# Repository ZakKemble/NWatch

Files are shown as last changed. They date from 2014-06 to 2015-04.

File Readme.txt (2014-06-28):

N|Watch - DIY Digital Wristwatch
http://blog.zakkemble.co.uk/diy-digital-wristwatch/

The firmware .hex and .eep files are compiled for ATmega328P

Fuses for ATmega328/328P
Internal RC 8MHz 6 CK/14CK + 65ms startup
Bootloader enabled, 256 words (512 bytes)
Serial program (SPI) enabled
Brown-out at 1.8V
High:		0xDE
Low:		0xE2
Extended:	0x06

./utils/bitmapConverter.exe
Utility to convert images (in ./imgs/) to pixel byte array

Font used for the large numbers on the main time display is AgencyFB Bold Wide available at http://www.fontsner.com/font/AgencyFBBoldWide-37966.html
My productions are published under GNU GPL v3 (see License.txt).

--------

Zak Kemble
contact@zakkemble.co.uk

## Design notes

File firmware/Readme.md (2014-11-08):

About these hex and eep files
=============================

### optiboot.hex
Optiboot UART bootloader. Baud set to 57600 for maximum compatibility.

### optiboot_superspeed.hex
Optiboot UART bootloader. Baud set to 1000000 which is the fastest an 8MHz AVR can run its UART at. Reduces upload time from ~14 seconds to ~5 seconds (27174 bytes).  
Tested on Windows and Linux with CH340G USB-serial converter. Should work with most other converters. However AVRDUDE on Linux needs a minor modification to support 1Mb, see this - https://github.com/zkemble/avrdude/tree/custombaud

### watch_eng.hex
The main program in English.

### watch_rus.hex
The main program in Russian.

### watch.eep
EEPROM data. This must be uploaded along with `watch_(lang).hex`, it contains the beep tunes and other bits of data.

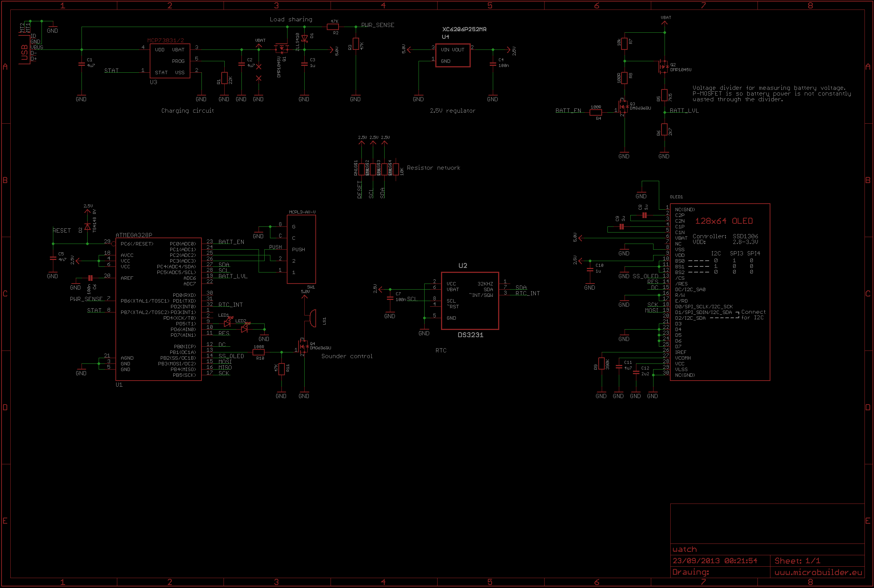
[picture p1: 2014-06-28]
hardware/watch/1.1/schematic.png

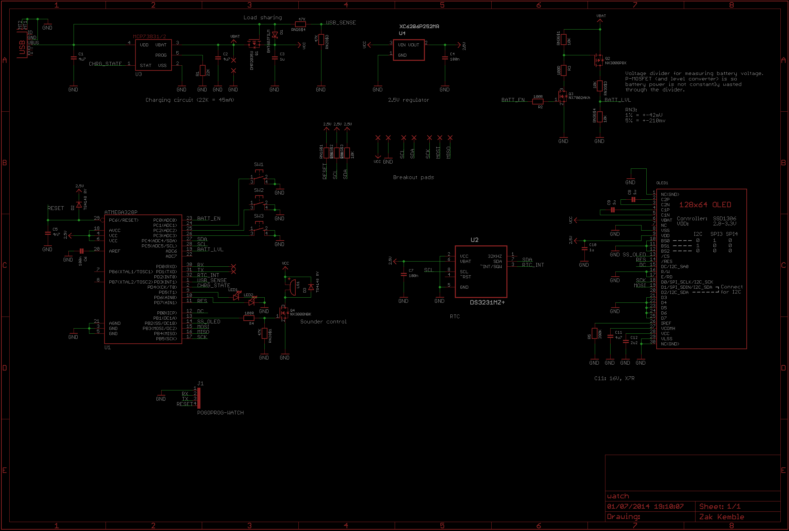
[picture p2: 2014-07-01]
hardware/watch/1.3/schematic.png

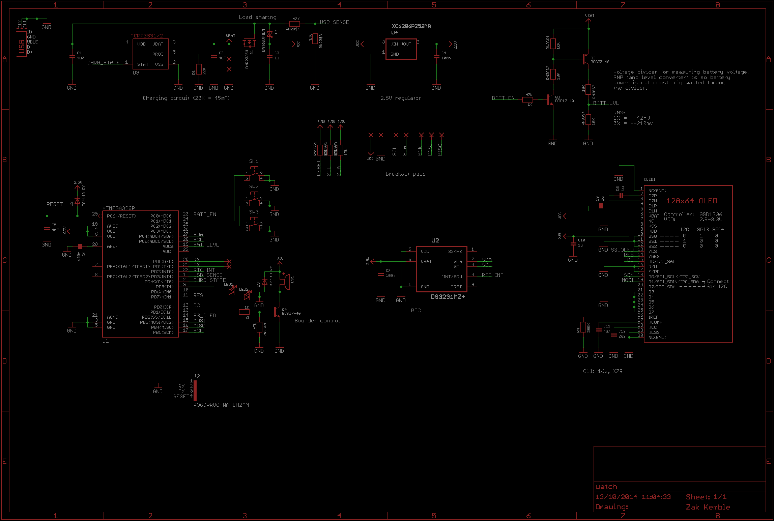
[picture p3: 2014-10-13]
hardware/watch/1.4/schematic.png

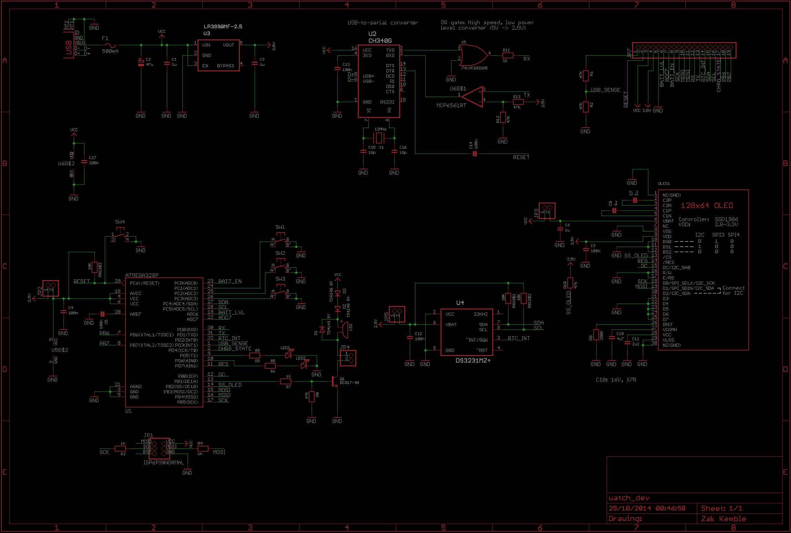
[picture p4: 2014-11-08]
hardware/dev/1.1/schematic.png

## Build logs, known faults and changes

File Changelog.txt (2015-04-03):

2015-04-03:
	Software:
	- Added support for SH1106 OLEDs, see OLED_CONTROLLER in config.h

2014-11-15:
	Software:
	- Fixed issue for when RTC isn't connected

2014-11-08:
	Software:
	- Updated Russian translation (day of week images)

	Hardware:
	- Released N|WatchDev designs (dev board version of the watch)

2014-10-29:
	Software:
	- Added 12 hour time option
	- Russian translation, thanks to Onatsky Sergei (Le_Fleurs (-at-) mail (-dot-) ru)
	- Bootloader baud changed from 76800 to 57600 (Linux doesn't like 76800)

2014-10-20:
	Software:
	- Fixed alarm bug

2014-10-13:
	Software:
	- Added early battery undervoltage cutoff. Improves battery lifespan by not letting the voltage go so low and the RTC will continue working since the battery's own PCM hasn't kicked in yet
	- Slightly reduced power consumption by going into power save sleep instead of idle sleep if no other peripherals are in use
	- Various code optimisations

	Hardware:
	N|Watch (v1.4):
	- Q2, Q3, Q4 MOSFETs changed to BJTs (BC817-40 & BC807-40)
	- R2, R3 100R gate resistors changed to 47K and 1K
	- R4 has been removed (now all resistors in RN3 are being used)
	- Pogo pads are now 2mm apart instead of 1.27mm (was hard to solder the pogo adapter)

2014-06-30:
	Software:
	- Fixed tune priority not resetting

2014-06-28:
	Software:
	- Added a bootloader (slightly modified Optiboot, added support for ATmega328 non-P and reading/writing EEPROM)
	- Reduced flash and RAM usage (Flash: 29156 -> 26702 (2454), RAM: 1407 -> 1300 (107))
	- Added support for playing tunes
	- Alarms are loaded from EEPROM as needed instead of having them hanging around in RAM all the time
	- Lots of bug fixes, heres some:
		Wonkiness if EEPROM wasn't programmed
		Alarms not going off on the correct day
		If an alarm goes off but is not cancelled by the user the watch would stay on
		Watch waking up when it's not supposed to
	- Bunch more stuff...

	Hardware:
	N|Watch (v1.3):
	- 3 Separate buttons instead of a 3 way nav button
	- MOSFETs have been changed to more suitable types (DMG6968s were total overkill)
	- Thinner PCB traces allowing components to be packed closer together
	- Breakout pads for power, I2C, UART and SPI

2013-09-25:
	- Initial release

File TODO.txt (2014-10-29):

global.c system.c pwrmgr.c - fix up this code! lots of little (but rare) issues with interrupts happening just before going to power down sleep
draw.c - also fix up this, cleanup that struct image_s stuff and maybe convert draw_bitmap_do() to ASM to see if its any faster?
millis.c/millis_isr.s - use flags that are processed in the ISR instead? also reduce millis resolution to 4ms? nothing in the code really needs 1ms res
bool/BOOL

Make a better readme
Arduino stuff

Alarm snooze
Options for alarm snooze
Improve alarms menu
	- Use new WE/TU icon things
Improve games menu
Options for setting what up and down buttons do when on the main watch display (open stopwatch/alarms/games etc)
Make menu option name animated, move off then back on or something
sleep mode options
	- Off
	- Low power (dim screen)
Reduce CPU clock if animations are disabled (and at other times too?)
Update the display less often (saves power)
	- Only draw when needed
	- Seperate logic and drawing
Sometimes the sounder 'pops' due to bad waveform output
Options for LEDs (brightness etc)
Fancy USB plugged in screen anim?
Countdown timer
More games?
Option to return to main diplay after going into standby

Finish support for DS1307, MCP7940x and internal RTC sources
Finish support for LED flash patterns
Something to show sunrise and sunset times? User will need to enter their latitude.
Record time of USB unplug

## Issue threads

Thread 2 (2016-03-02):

cant wake from sleep,uses lots of battery too

dunk8888, 2016-03-02:
how do i wake watch from screen off sleep mode,no buttons seem to wake it up.

zkemble, 2016-03-05:
Any button press should wake the watch. Do all of the buttons work when the watch is on?

dunk8888, 2016-03-05:
yes all buttons work,this is only pcb desighn,i use it as a little allarm
clock and it seems to use a 300mah battery overnight even when screen is
off,if i leave for more than a few minutes it doesnt like to wake up,i have
to pull battery then plug back in,i love the car game by the way,i love the
hole thing,verry smart indeed.

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

zkemble, 2016-03-05:
Thanks :D Hmm, did you load the .eep file? Maybe double check for any short circuits too. What's the current draw from the battery like?

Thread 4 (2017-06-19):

Code...

lechatvert, 2017-06-19:
I can't seem to find the exact code for this watch. I really like the interface but I'm just a beginner so I can't really do it. If you can, I would highly appreciate having the code so I can make this watch. Also, if you can, I would like having instructions on how to make it with an Arduino, since it's a lot easier to use. I'm planning to use the Pro Mini or the Pro Micro. Thanks in advance.

lechatvert, 2017-06-20:
Oh, by the way, I just saw the closed issue about arduinos. But, if possible, can you explain to me how to flash the code on the chip and what I will need to flash it.

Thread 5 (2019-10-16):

im noob ..error

cheese0307, 2019-10-16:
C:\Users\ADMINI~1\AppData\Local\Temp\cc9zl9qr.ltrans0.ltrans.o: In function `oled_flush':

C:\Users\ADMINI~1\AppData\Local\Temp\arduino_build_31448\sketch/oled.c:108: undefined reference to `spi_transfer_nr'

C:\Users\ADMINI~1\AppData\Local\Temp\arduino_build_31448\sketch/oled.c:109: undefined reference to `spi_transfer_nr'

C:\Users\ADMINI~1\AppData\Local\Temp\arduino_build_31448\sketch/oled.c:110: undefined reference to `spi_transfer_nr'

C:\Users\ADMINI~1\AppData\Local\Temp\arduino_build_31448\sketch/oled.c:112: undefined reference to `spi_transfer_nr'

C:\Users\ADMINI~1\AppData\Local\Temp\arduino_build_31448\sketch/oled.c:113: undefined reference to `spi_transfer_nr'

C:\Users\ADMINI~1\AppData\Local\Temp\cc9zl9qr.ltrans0.ltrans.o:C:\Users\ADMINI~1\AppData\Local\Temp\arduino_build_31448\sketch/oled.c:114: more undefined references to `spi_transfer_nr' follow

collect2.exe: error: ld returned 1 exit status

exit status 1
为开发板 Arduino Leonardo 编译时出错。

zkemble, 2019-10-16:
N|Watch is not an Arduino compatible project. You need to use [Atmel Studio](https://www.microchip.com/mplab/avr-support/atmel-studio-7).

Closed 2019-10-17.

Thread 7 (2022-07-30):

Fuses for ATmega328/328P

7918514, 2022-07-30:
You have fuses:
High: 0xDE
Low: 0xE2
Extended: 0x06
This is right? These fuses are for external quartz.

ZakKemble, 2022-07-30:
No, they're correct. I think you have got the high and low fuses mixed up.

7918514, 2022-07-30:
I beg your pardon. You're right. I looked carelessly. I'm used to Low, High, Extended.
Thanks!

Closed 2022-07-30.

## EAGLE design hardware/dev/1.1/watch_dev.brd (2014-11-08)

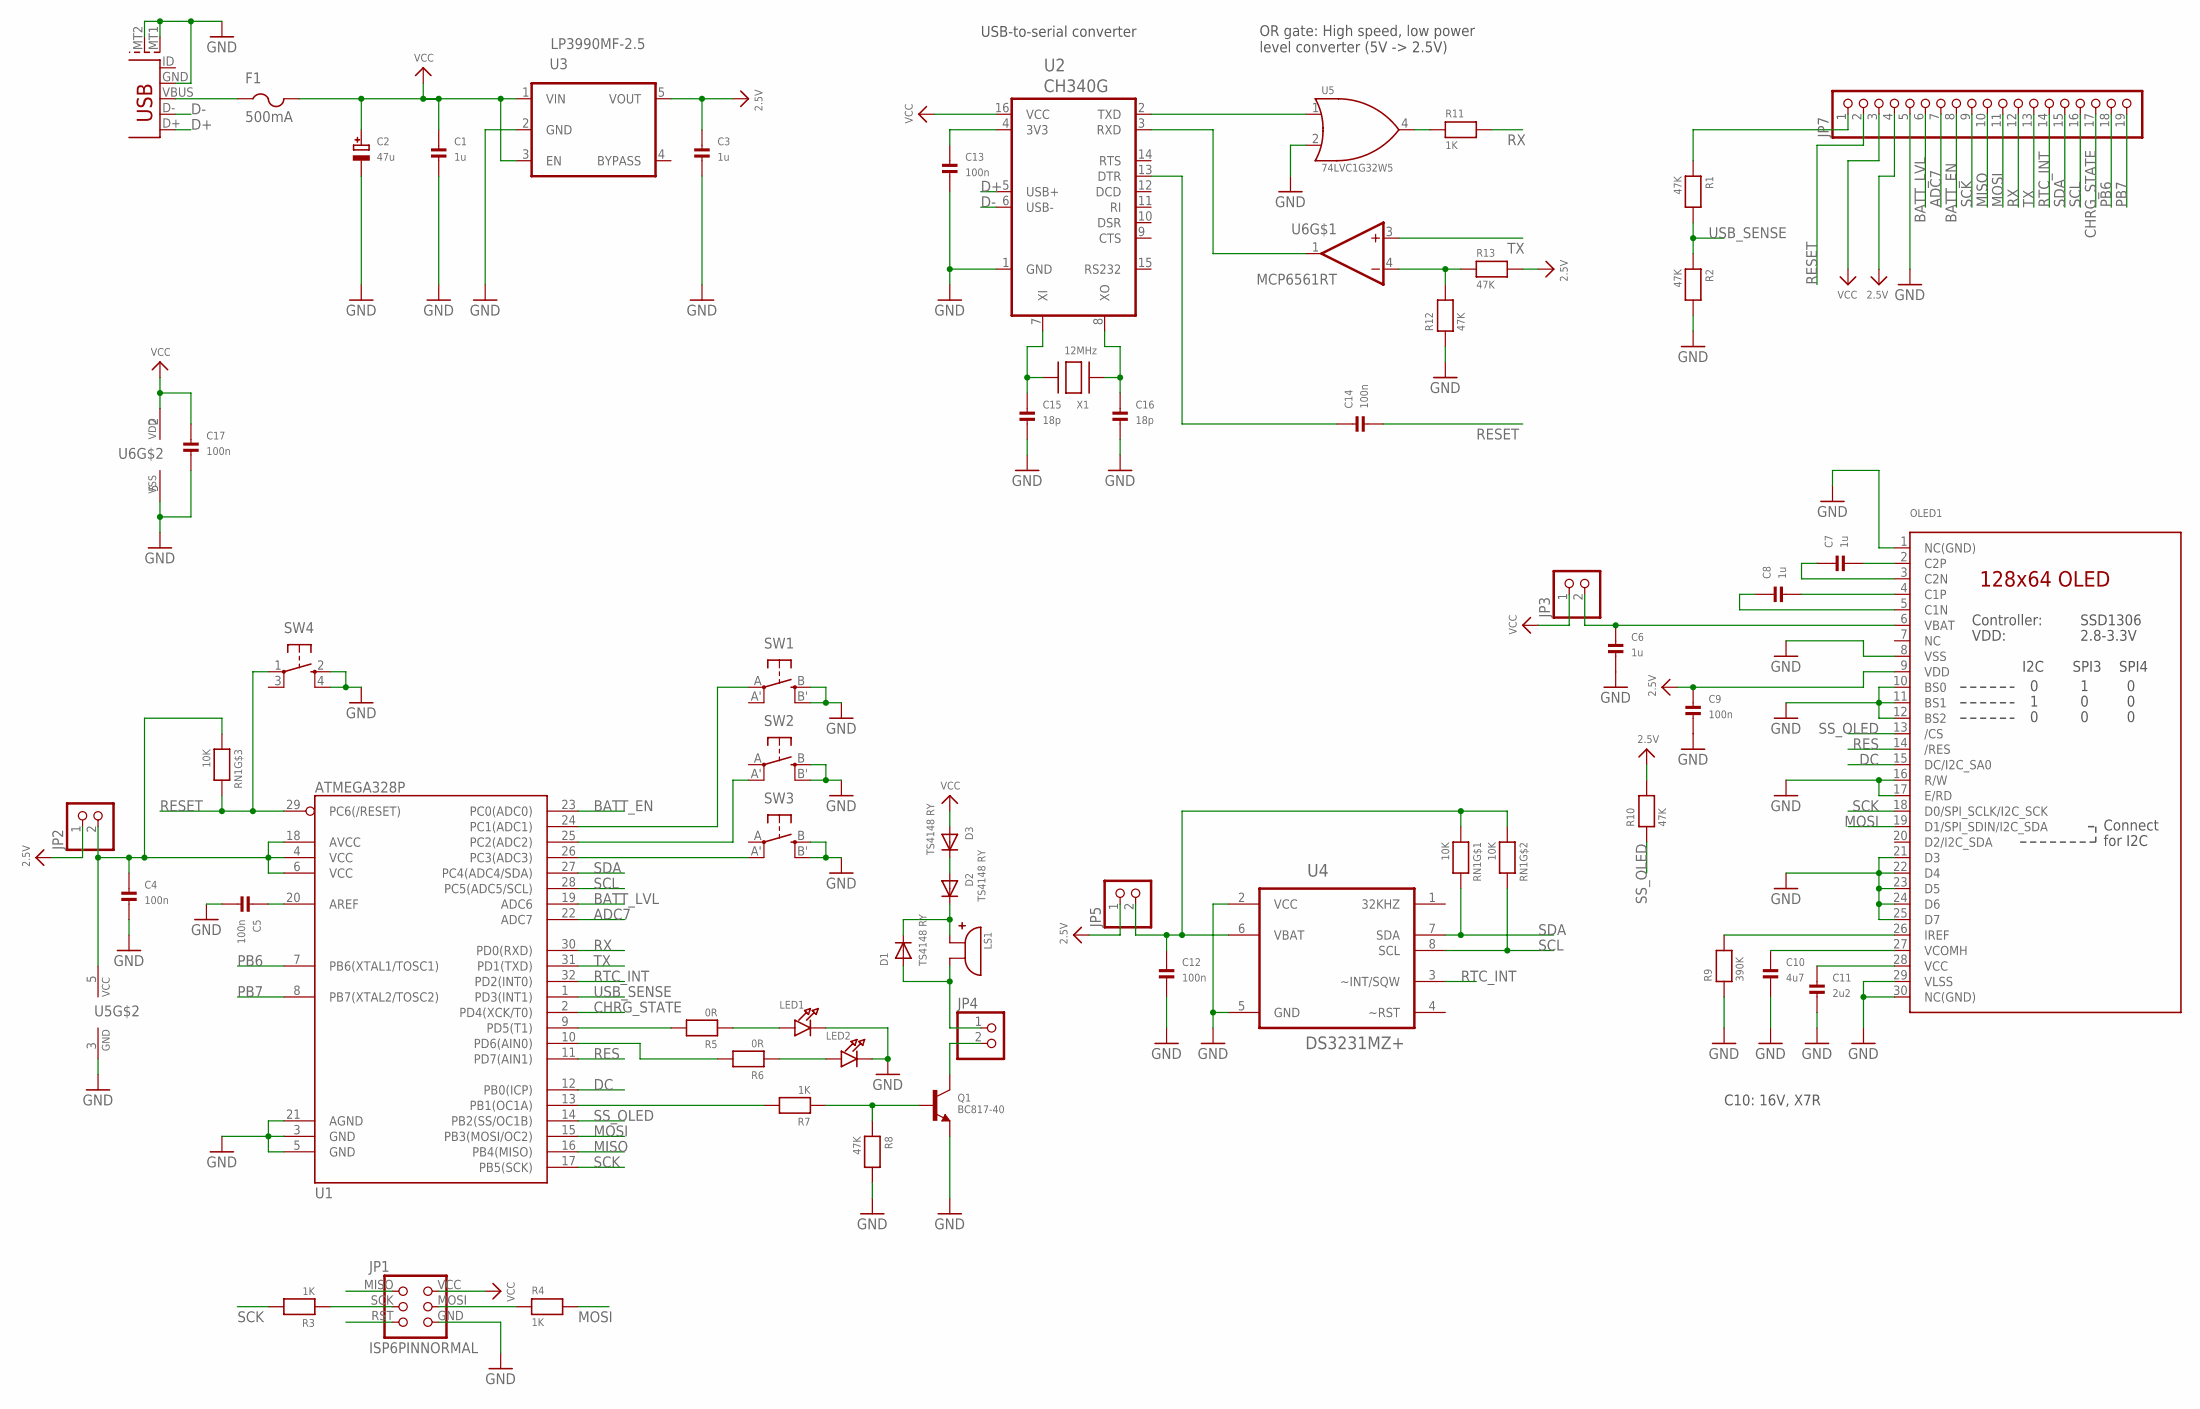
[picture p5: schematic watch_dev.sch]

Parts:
C1, C3, C6, C7, C8: 1u; 0805
C2: 47u; PANASONIC_C
C4, C5, C9, C12, C13, C14, C17: 100n; 0805
C10: 4u7; 0805
C11: 2u2; 0805
C15, C16: 18p; 0805
D1, D2, D3: TS4148 RY; 0805_DIODE
F1: 500mA; 1206
JP1: ISP6PINNORMAL; ISP6PIN
JP2, JP3, JP4, JP5: PINHD-1X2; 1X02
JP7: PINHD-1X19; 1X19
LED1, LED2: LED0805; CHIPLED_0805
LS1: ABMT-801-RC; PIEZO
OLED1: DISP_OLED_UG-2864HSWEG01_NOOUTLINE; UG-2864HSWEG01_1.3_WRAPAROUND
Q1: BC817-40; SOT23-WIDE
R1, R2, R8, R10, R12, R13: 47K; 0805
R3, R4, R7, R11: 1K; 0805
R5, R6: 0R; 0805
R9: 390K; 0805
RN1: 10K; RESPACK_4X0603
SW1, SW2, SW3: SPST_TACTMC32882; TACT_SMD4
SW4: SPST_TACTKMR2; KMR2
U1: ATMEGA328P; TQFP32-08
U2: CH340G; SOIC16_SMPAD
U3: LP3990MF-2.5; SOT95P275X110-5N
U4: DS3231MZ+; SOIC8_150MIL_SMPAD
U5: 74LVC1G32W5; SOT95P275X110-5N
U6: MCP6561RT; SOT95P275X110-5N
USB1: USB-MICROBLARGEPAD; USB-MICROB_LARGEPAD
X1: 12MHz; NX5032

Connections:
2.5V: C3.1, C9.1, JP2.1, JP5.1, JP7.4, OLED1.9 (VDD), R10.2, R13.2, U3.5 (VOUT)
ADC7: JP7.7, U1.22 (ADC7)
BATT_EN: JP7.8, U1.23 (PC0(ADC0))
BATT_LVL: JP7.6, U1.19 (ADC6)
CHRG_STATE: JP7.17, U1.2 (PD4(XCK/T0))
D+: U2.5 (USB+), USB1.D+
D-: U2.6 (USB-), USB1.D-
DC: OLED1.15 (DC/I2C_SA0), U1.12 (PB0(ICP))
GND: C1.2, C2.-, C3.2, C4.2, C5.2, C6.2, C9.2, C10.2, C11.2, C12.2, C13.2, C15.2, C16.2, C17.2, JP1.GND (6), JP7.5, LED1.C, LED2.C, OLED1.1 (NC(GND)), OLED1.8 (VSS), OLED1.10 (BS0), OLED1.11 (BS1), OLED1.12 (BS2), OLED1.16 (R/W), OLED1.17 (E/RD), OLED1.21 (D3), OLED1.22 (D4), OLED1.23 (D5), OLED1.24 (D6), OLED1.25 (D7), OLED1.29 (VLSS), OLED1.30 (NC(GND)), Q1.2 (E), R2.2, R8.2, R9.1, R12.1, SW1.B (S), SW1.B' (S1), SW2.B (S), SW2.B' (S1), SW3.B (S), SW3.B' (S1), SW4.2 (S), SW4.4 (S1), U1.3 (GND), U1.5 (GND), U1.21 (AGND), U2.1 (GND), U3.2 (GND), U4.2 (VCC), U4.5 (GND), U5.2 (B), U5.3 (GND), U6.5 (VSS), USB1.GND, USB1.MT1 (SHEILD1), USB1.MT2 (SHEILD2)
MISO: JP1.MISO (1), JP7.10, U1.16 (PB4(MISO))
MOSI: JP7.11, OLED1.19 (D1/SPI_SDIN/I2C_SDA), R4.2, U1.15 (PB3(MOSI/OC2))
unnamed: C5.1, U1.20 (AREF)
unnamed: SW1.A, U1.24 (PC1(ADC1))
unnamed: C7.2, OLED1.2 (C2P)
unnamed: SW3.A' (P1), U1.26 (PC3(ADC3))
unnamed: OLED1.26 (IREF), R9.2
unnamed: JP7.1, R1.1
unnamed: D1.1 (A), JP4.1, LS1.2 (GND)
unnamed: Q1.1 (B), R7.1, R8.1
unnamed: SW2.A' (P1), U1.25 (PC2(ADC2))
unnamed: F1.1, USB1.VBUS
unnamed: R5.2, U1.9 (PD5(T1))
unnamed: C6.1, JP3.2, OLED1.6 (VBAT)
unnamed: C8.1, OLED1.5 (C1N)
unnamed: C8.2, OLED1.4 (C1P)
unnamed: C7.1, OLED1.3 (C2N)
unnamed: R6.2, U1.10 (PD6(AIN0))
unnamed: C4.1, JP2.2, RN1.3 (1), U1.4 (VCC), U1.6 (VCC), U1.18 (AVCC), U5.5 (VCC)
unnamed: JP4.2, Q1.3 (C)
unnamed: C10.1, OLED1.27 (VCOMH)
unnamed: C11.1, OLED1.28 (VCC)
unnamed: C15.1, U2.7 (XI), X1.P$2
unnamed: JP1.SCK (3), R3.1
unnamed: C16.1, U2.8 (XO), X1.P$1
unnamed: JP1.MOSI (4), R4.1
unnamed: C13.1, U2.4 (3V3)
unnamed: U2.2 (TXD), U5.1 (A)
unnamed: R11.1, U5.4 (Y)
unnamed: LED1.A, R5.1
unnamed: LED2.A, R6.1
unnamed: C14.1, U2.13 (DTR)
unnamed: C12.1, JP5.2, RN1.1, RN1.2 (1), U4.6 (VBAT)
unnamed: D1.2 (C), D2.2 (C), LS1.1 (VCC)
unnamed: D2.1 (A), D3.2 (C)
unnamed: U2.3 (RXD), U6.1 (OUT)
unnamed: R12.2, R13.1, U6.4 (-IN)
PB6: JP7.18, U1.7 (PB6(XTAL1/TOSC1))
PB7: JP7.19, U1.8 (PB7(XTAL2/TOSC2))
PIEZO: R7.2, U1.13 (PB1(OC1A))
RES: OLED1.14 (/RES), U1.11 (PD7(AIN1))
RESET: C14.2, JP1.RST (5), JP7.2, RN1.6 (2), SW4.1, U1.29 (PC6(/RESET))
RTC_INT: JP7.14, U1.32 (PD2(INT0)), U4.3 (~INT/SQW)
RX: JP7.12, R11.2, U1.30 (PD0(RXD))
SCK: JP7.9, OLED1.18 (D0/SPI_SCLK/I2C_SCK), R3.2, U1.17 (PB5(SCK))
SCL: JP7.16, RN1.7 (2), U1.28 (PC5(ADC5/SCL)), U4.8 (SCL)
SDA: JP7.15, RN1.8 (2), U1.27 (PC4(ADC4/SDA)), U4.7 (SDA)
SS_OLED: OLED1.13 (/CS), R10.1, U1.14 (PB2(SS/OC1B))
TX: JP7.13, U1.31 (PD1(TXD)), U6.3 (+IN)
USB_SENSE: R1.2, R2.1, U1.1 (PD3(INT1))
VCC: C1.1, C2.+, C17.1, D3.1 (A), F1.2, JP1.VCC (2), JP3.1, JP7.3, U2.16 (VCC), U3.1 (VIN), U3.3 (EN), U6.2 (VDD)

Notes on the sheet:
C10: 16V, X7R
USB-to-serial converter
OR gate: High speed, low power level converter (5V -> 2.5V)

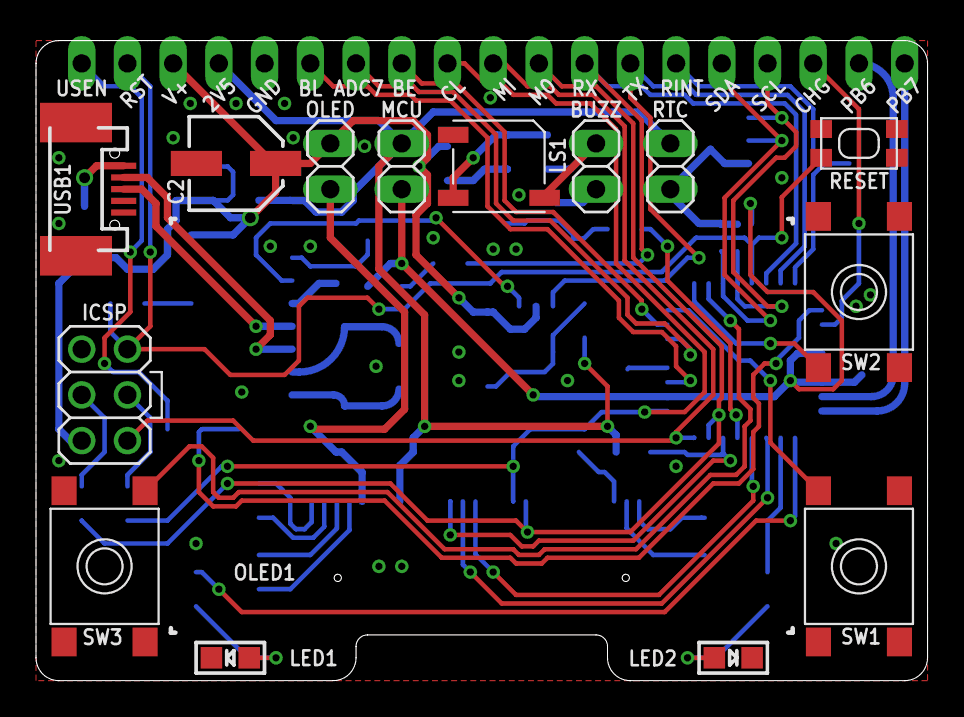
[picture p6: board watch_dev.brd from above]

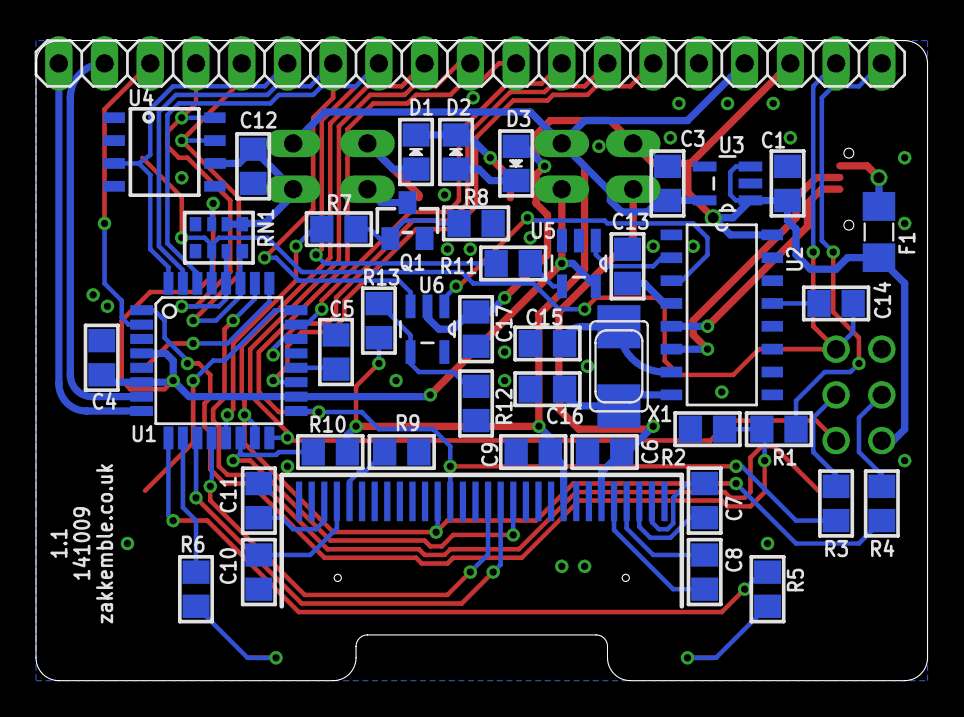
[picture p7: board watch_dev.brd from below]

Board: 2 copper layers, 49.5 x 35.6 mm, 58 parts (43 on the bottom side), 60 nets.

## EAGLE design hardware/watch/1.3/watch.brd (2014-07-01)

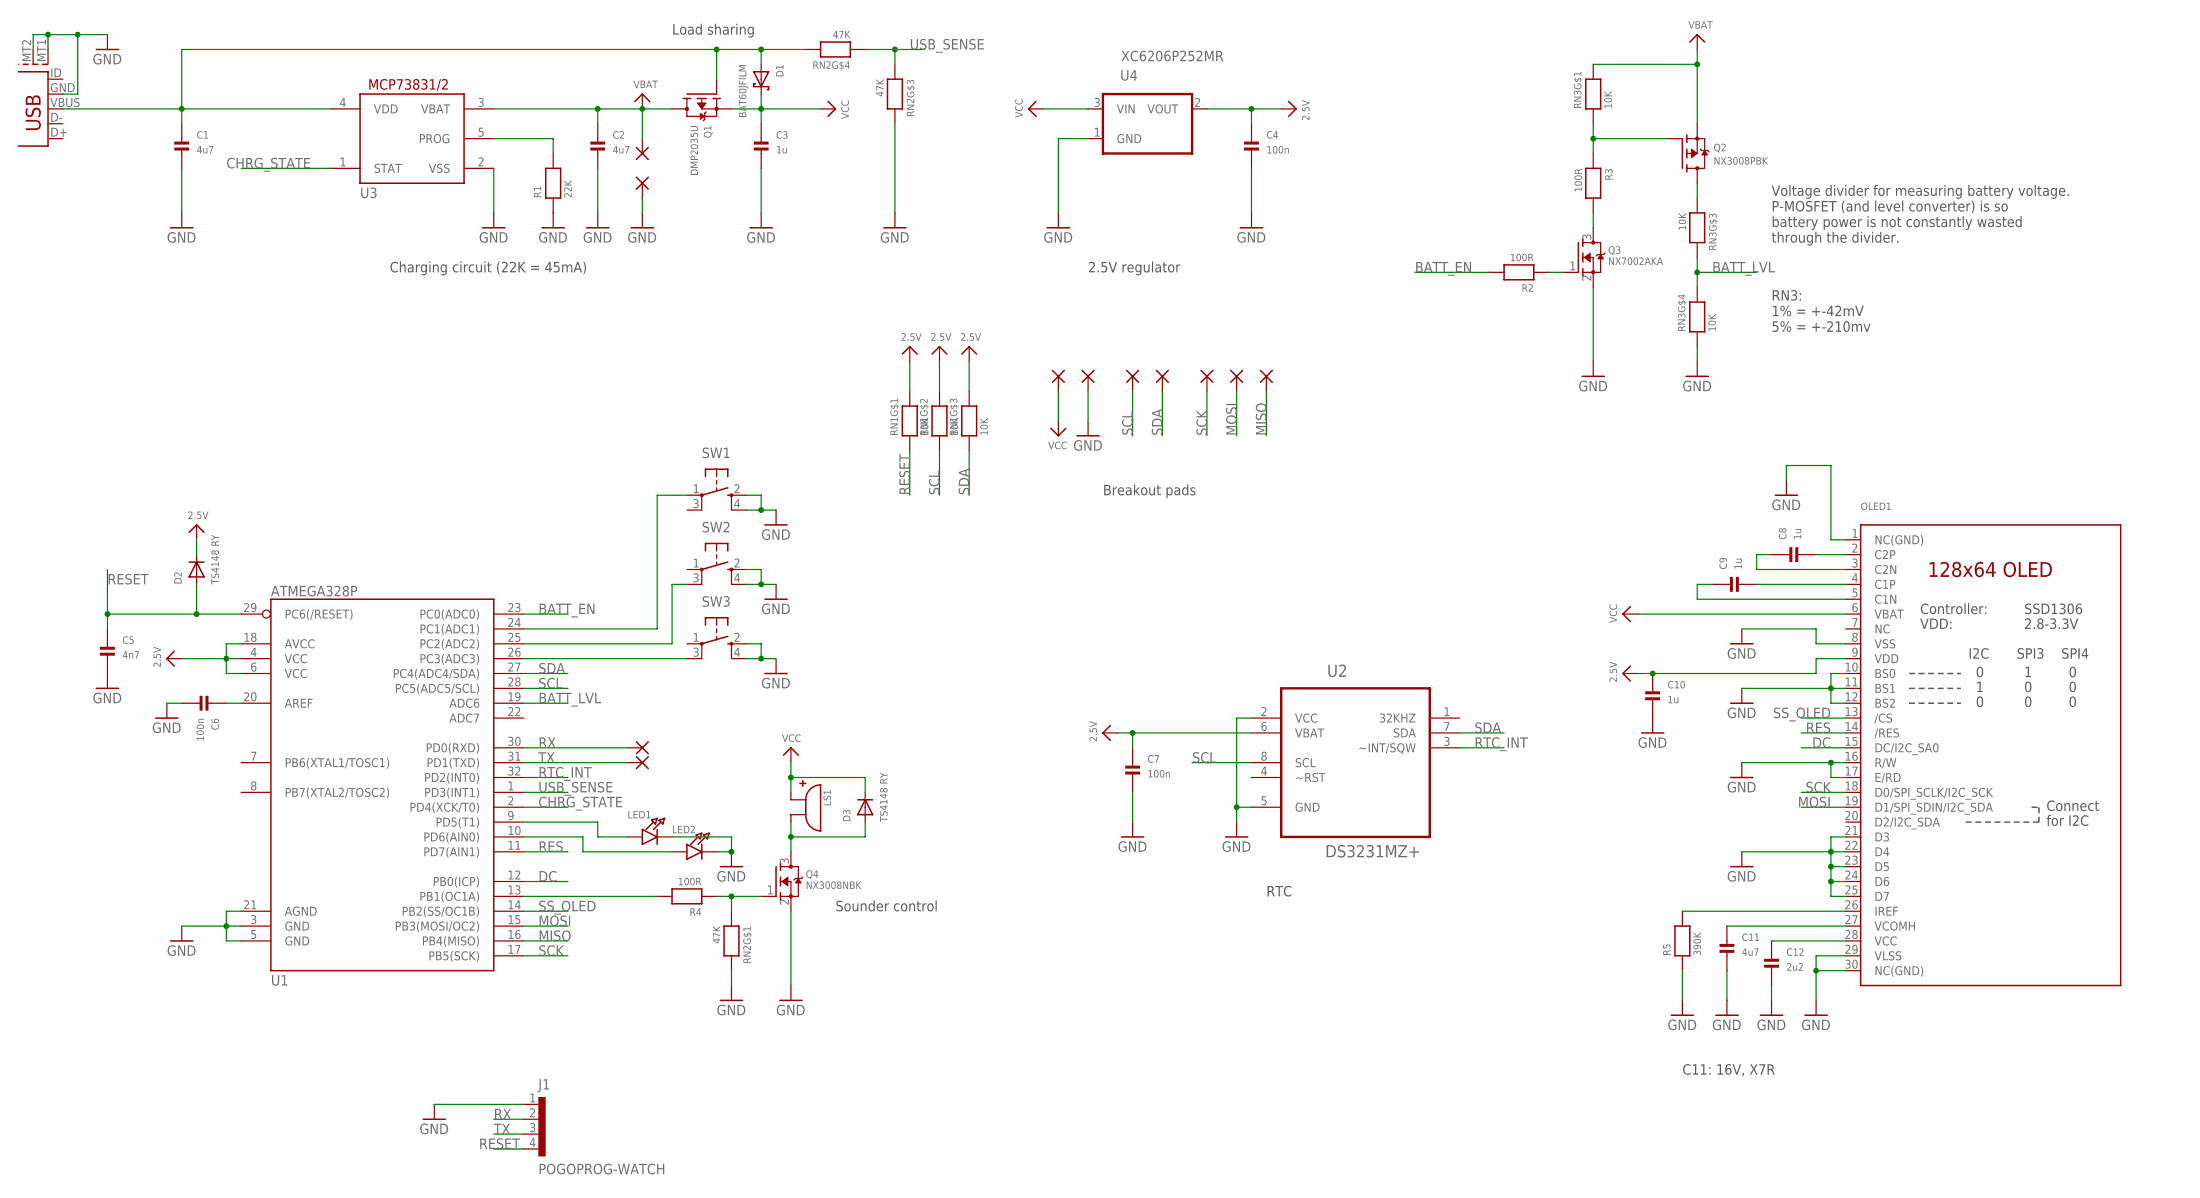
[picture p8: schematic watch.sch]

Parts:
C1, C2, C11: 4u7; 0805
C3, C8, C9, C10: 1u; 0805
C4, C6, C7: 100n; 0805
C5: 4n7; 0805
C12: 2u2; 0805
D1: BAT60JFILM; SOD-323
D2, D3: TS4148 RY; DIODE0805
J1: POGOPROG-WATCH; POGOPROG_WATCH
LED1, LED2: LED0805; CHIPLED_0805
LS1: ABMT-801-RC; PIEZO
OLED1: DISP_OLED_UG-2864HSWEG01_NOOUTLINEWATCH; UG-2864HSWEG01_1.3_WRAPAROUND_WATCH
PAD1, PAD2, PAD3, PAD4, PAD5, PAD6, PAD7, PAD8, PAD10, PAD11, PAD12: SMD2; SMD1,27-2,54
Q1: DMP2035U; SOT23-WIDE
Q2: NX3008PBK; SOT23-WIDE
Q3: NX7002AKA; SOT23-WIDE
Q4: NX3008NBK; SOT23-WIDE
R1: 22K; 0805
R2, R3, R4: 100R; 0805
R5: 390K; 0805
RN1, RN3: 10K; RESPACK_4X0603
RN2: 47K; RESPACK_4X0603
SW1, SW2, SW3: SPST_TACTRA; TACT_SMD2
U1: ATMEGA328P; TQFP32-08
U2: DS3231MZ+; SOIC8_150MIL
U3: MCP73832T-2ACI/OT; SOT23-5L
U4: XC6206P252MR; SOT-23
USB1: USB-MICROBLARGEPAD; USB-MICROB_LARGEPAD

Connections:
2.5V: C4.1, C7.1, C10.1, D2.2 (C), OLED1.9 (VDD), RN1.6 (2), RN1.7 (2), RN1.8 (2), U1.4 (VCC), U1.6 (VCC), U1.18 (AVCC), U2.6 (VBAT), U4.2 (VOUT)
BATT_EN: R2.2, U1.23 (PC0(ADC0))
BATT_LVL: RN3.5 (2), RN3.6 (2), U1.19 (ADC6)
CHRG_STATE: U1.2 (PD4(XCK/T0)), U3.1 (STAT)
DC: OLED1.15 (DC/I2C_SA0), U1.12 (PB0(ICP))
GND: C1.2, C2.2, C3.2, C4.2, C5.2, C6.2, C7.2, C10.2, C11.2, C12.2, J1.1, LED1.C, LED2.C, OLED1.1 (NC(GND)), OLED1.8 (VSS), OLED1.10 (BS0), OLED1.11 (BS1), OLED1.12 (BS2), OLED1.16 (R/W), OLED1.17 (E/RD), OLED1.21 (D3), OLED1.22 (D4), OLED1.23 (D5), OLED1.24 (D6), OLED1.25 (D7), OLED1.29 (VLSS), OLED1.30 (NC(GND)), PAD2.1, PAD5.1, Q3.2 (S), Q4.2 (S), R1.1, R5.1, RN2.6 (2), RN2.8 (2), RN3.4 (1), SW1.2 (S), SW1.4 (S1), SW2.2 (S), SW2.4 (S1), SW3.2 (S), SW3.4 (S1), U1.3 (GND), U1.5 (GND), U1.21 (AGND), U2.2 (VCC), U2.5 (GND), U3.2 (VSS), U4.1 (GND), USB1.GND, USB1.MT1 (SHEILD1), USB1.MT2 (SHEILD2)
MISO: PAD12.1, U1.16 (PB4(MISO))
MOSI: OLED1.19 (D1/SPI_SDIN/I2C_SDA), PAD11.1, U1.15 (PB3(MOSI/OC2))
unnamed: C6.1, U1.20 (AREF)
unnamed: SW1.1, U1.24 (PC1(ADC1))
unnamed: C8.2, OLED1.2 (C2P)
unnamed: SW3.3 (P1), U1.26 (PC3(ADC3))
unnamed: OLED1.26 (IREF), R5.2
unnamed: C1.1, D1.A, Q1.1 (G), RN2.5 (2), U3.4 (VDD), USB1.VBUS
unnamed: D3.1 (A), LS1.2 (GND), Q4.3 (D)
unnamed: Q4.1 (G), R4.1, RN2.1
unnamed: SW2.3 (P1), U1.25 (PC2(ADC2))
unnamed: R1.2, U3.5 (PROG)
unnamed: LED1.A, U1.9 (PD5(T1))
unnamed: Q2.1 (G), R3.1, RN3.1
unnamed: C9.1, OLED1.5 (C1N)
unnamed: C9.2, OLED1.4 (C1P)
unnamed: C8.1, OLED1.3 (C2N)
unnamed: LED2.A, U1.10 (PD6(AIN0))
unnamed: Q3.3 (D), R3.2
unnamed: Q2.3 (D), RN3.3 (1)
unnamed: C11.1, OLED1.27 (VCOMH)
unnamed: C12.1, OLED1.28 (VCC)
unnamed: Q3.1 (G), R2.1
PIEZO: R4.2, U1.13 (PB1(OC1A))
RES: OLED1.14 (/RES), U1.11 (PD7(AIN1))
RESET: C5.1, D2.1 (A), J1.4, RN1.1, U1.29 (PC6(/RESET))
RTC_INT: U1.32 (PD2(INT0)), U2.3 (~INT/SQW)
RX: J1.2, PAD3.1, U1.30 (PD0(RXD))
SCK: OLED1.18 (D0/SPI_SCLK/I2C_SCK), PAD10.1, U1.17 (PB5(SCK))
SCL: PAD8.1, RN1.2 (1), U1.28 (PC5(ADC5/SCL)), U2.8 (SCL)
SDA: PAD7.1, RN1.3 (1), U1.27 (PC4(ADC4/SDA)), U2.7 (SDA)
SS_OLED: OLED1.13 (/CS), U1.14 (PB2(SS/OC1B))
TX: J1.3, PAD4.1, U1.31 (PD1(TXD))
USB_SENSE: RN2.3 (1), RN2.4 (1), U1.1 (PD3(INT1))
VBAT: C2.1, PAD1.1, Q1.3 (D), Q2.2 (S), RN3.8 (2), U3.3 (VBAT)
VCC: C3.1, D1.C, D3.2 (C), LS1.1 (VCC), OLED1.6 (VBAT), PAD6.1, Q1.2 (S), U4.3 (VIN)

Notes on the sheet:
Charging circuit (22K = 45mA)
2.5V regulator
Voltage divider for measuring battery voltage. P-MOSFET (and level converter) is so battery power is not constantly wasted through the divider.
RTC
Load sharing
Sounder control
C11: 16V, X7R
Breakout pads
RN3: 1% = +-42mV 5% = +-210mv

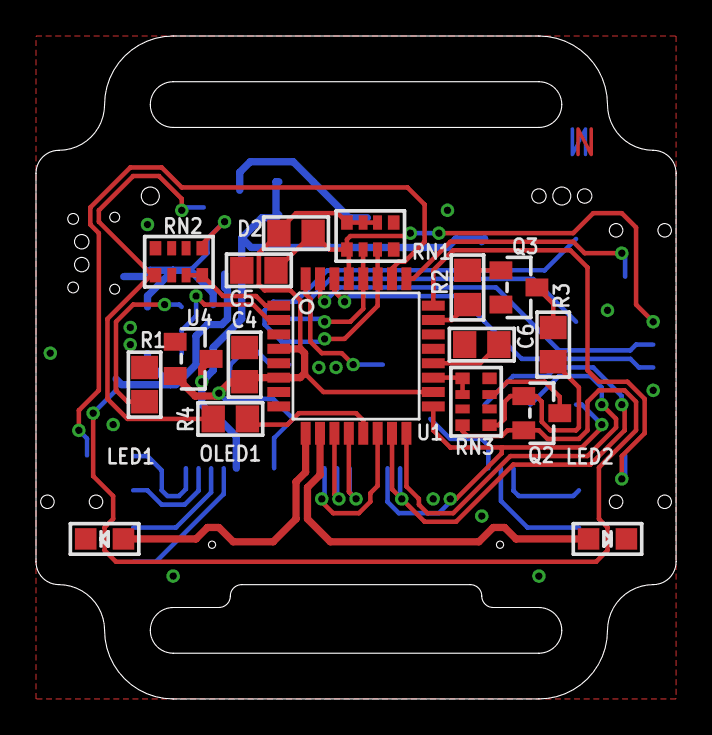
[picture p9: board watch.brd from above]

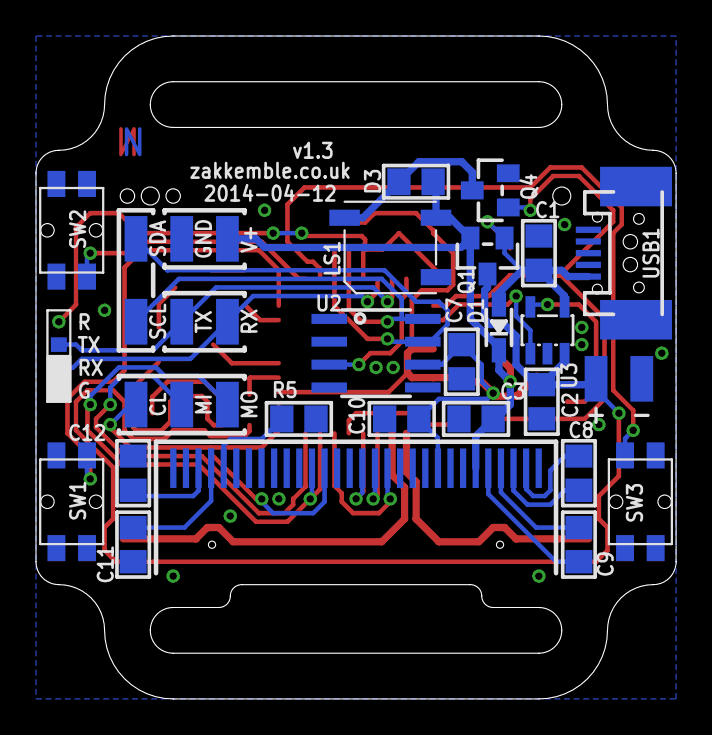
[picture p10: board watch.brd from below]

Board: 2 copper layers, 35.6 x 36.8 mm, 51 parts (33 on the bottom side), 42 nets.

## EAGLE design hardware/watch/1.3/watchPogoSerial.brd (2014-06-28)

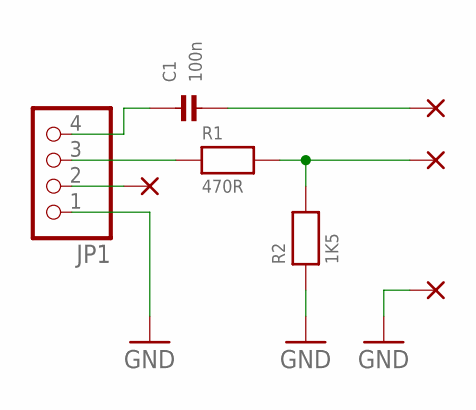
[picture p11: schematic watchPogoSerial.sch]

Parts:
C1: 100n; 0805
JP1: PINHD-1X4; 1X04
PAD1, PAD3, PAD6, PAD12: PAD0.7-LONG; PAD-0.75-LONG
R1: 470R; 0805
R2: 1K5; 0805

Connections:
GND: JP1.1, PAD1.P$1, R2.1
unnamed: C1.1, JP1.4
unnamed: C1.2, PAD3.P$1
unnamed: JP1.3, R1.1
unnamed: PAD6.P$1, R1.2, R2.2
unnamed: JP1.2, PAD12.P$1

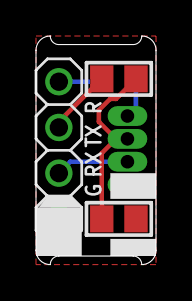
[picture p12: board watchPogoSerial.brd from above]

Board: 2 copper layers, 6.7 x 12.7 mm, 8 parts (1 on the bottom side), 6 nets.

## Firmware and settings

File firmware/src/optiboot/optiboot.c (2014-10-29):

/**********************************************************/
/* Optiboot bootloader for Arduino                        */
/*                                                        */
/* http://optiboot.googlecode.com                         */
/*                                                        */
/* Arduino-maintained version : See README.TXT            */
/* http://code.google.com/p/arduino/                      */
/*  It is the intent that changes not relevant to the     */
/*  Arduino production envionment get moved from the      */
/*  optiboot project to the arduino project in "lumps."   */
/*                                                        */
/* Heavily optimised bootloader that is faster and        */
/* smaller than the Arduino standard bootloader           */
/*                                                        */
/* Enhancements:                                          */
/*   Fits in 512 bytes, saving 1.5K of code space         */
/*   Background page erasing speeds up programming        */
/*   Higher baud rate speeds up programming               */
/*   Written almost entirely in C                         */
/*   Customisable timeout with accurate timeconstant      */
/*   Optional virtual UART. No hardware UART required.    */
/*   Optional virtual boot partition for devices without. */
/*                                                        */
/* What you lose:                                         */
/*   Implements a skeleton STK500 protocol which is       */
/*     missing several features including EEPROM          */
/*     programming and non-page-aligned writes            */
/*   High baud rate breaks compatibility with standard    */
/*     Arduino flash settings                             */
/*                                                        */
/* Fully supported:                                       */
/*   ATmega168 based devices  (Diecimila etc)             */
/*   ATmega328P based devices (Duemilanove etc)           */
/*                                                        */
/* Beta test (believed working.)                          */
/*   ATmega8 based devices (Arduino legacy)               */
/*   ATmega328 non-picopower devices                      */
/*   ATmega644P based devices (Sanguino)                  */
/*   ATmega1284P based devices                            */
/*   ATmega1280 based devices (Arduino Mega)              */
/*                                                        */
/* Alpha test                                             */
/*   ATmega32                                             */
/*                                                        */
/* Work in progress:                                      */
/*   ATtiny84 based devices (Luminet)                     */
/*                                                        */
/* Does not support:                                      */
/*   USB based devices (eg. Teensy, Leonardo)             */
/*                                                        */
/* Assumptions:                                           */
/*   The code makes several assumptions that reduce the   */
/*   code size. They are all true after a hardware reset, */
/*   but may not be true if the bootloader is called by   */
/*   other means or on other hardware.                    */
/*     No interrupts can occur                            */
/*     UART and Timer 1 are set to their reset state      */
/*     SP points to RAMEND                                */
/*                                                        */
/* Code builds on code, libraries and optimisations from: */
/*   stk500boot.c          by Jason P. Kyle               */
/*   Arduino bootloader    http://arduino.cc              */
/*   Spiff's 1K bootloader http://spiffie.org/know/arduino_1k_bootloader/bootloader.shtml */
/*   avr-libc project      http://nongnu.org/avr-libc     */
/*   Adaboot               http://www.ladyada.net/library/arduino/bootloader.html */
/*   AVR305                Atmel Application Note         */
/*                                                        */
/* This program is free software; you can redistribute it */
/* and/or modify it under the terms of the GNU General    */
/* Public License as published by the Free Software       */
/* Foundation; either version 2 of the License, or        */
/* (at your option) any later version.                    */
/*                                                        */
/* This program is distributed in the hope that it will   */
/* be useful, but WITHOUT ANY WARRANTY; without even the  */
/* implied warranty of MERCHANTABILITY or FITNESS FOR A   */
/* PARTICULAR PURPOSE.  See the GNU General Public        */
/* License for more details.                              */
/*                                                        */
/* You should have received a copy of the GNU General     */
/* Public License along with this program; if not, write  */
/* to the Free Software Foundation, Inc.,                 */
/* 59 Temple Place, Suite 330, Boston, MA  02111-1307 USA */
/*                                                        */
/* Licence can be viewed at                               */
/* http://www.fsf.org/licenses/gpl.txt                    */
/*                                                        */
/**********************************************************/


/**********************************************************/
/*                                                        */
/* Optional defines:                                      */
/*                                                        */
/**********************************************************/
/*                                                        */
/* BIG_BOOT:                                              */
/* Build a 1k bootloader, not 512 bytes. This turns on    */
/* extra functionality.                                   */
/*                                                        */
/* BAUD_RATE:                                             */
/* Set bootloader baud rate.                              */
/*                                                        */
/* LUDICROUS_SPEED:                                       */
/* 230400 baud :-)                                        */
/*                                                        */
/* SOFT_UART:                                             */
/* Use AVR305 soft-UART instead of hardware UART.         */
/*                                                        */
/* LED_START_FLASHES:                                     */
/* Number of LED flashes on bootup.                       */
/*                                                        */
/* LED_DATA_FLASH:                                        */
/* Flash LED when transferring data. For boards without   */
/* TX or RX LEDs, or for people who like blinky lights.   */
/*                                                        */
/* SUPPORT_EEPROM:                                        */
/* Support reading and writing from EEPROM. This is not   */
/* used by Arduino, so off by default.                    */
/*                                                        */
/* TIMEOUT_MS:                                            */
/* Bootloader timeout period, in milliseconds.            */
/* 500,1000,2000,4000,8000 supported.                     */
/*                                                        */
/* UART:                                                  */
/* UART number (0..n) for devices with more than          */
/* one hardware uart (644P, 1284P, etc)                   */
/*                                                        */
/**********************************************************/


/**********************************************************/
/* Version Numbers!                                       */
/*                                                        */
/* Arduino Optiboot now includes this Version number in   */
/* the source and object code.                            */
/*                                                        */
/* Version 3 was released as zip from the optiboot        */
/*  repository and was distributed with Arduino 0022.     */
/* Version 4 starts with the arduino repository commit    */
/*  that brought the arduino repository up-to-date with   */
/*  the optiboot source tree changes since v3.            */
/* Version 5 was created at the time of the new Makefile  */
/*  structure (Mar, 2013), even though no binaries changed*/
/* It would be good if versions implemented outside the   */
/*  official repository used an out-of-seqeunce version   */
/*  number (like 104.6 if based on based on 4.5) to       */
/*  prevent collisions.                                   */
/*                                                        */
/**********************************************************/

/**********************************************************/
/* Edit History:					  */
/*							  */
/* Mar 2013                                               */
/* 5.0 WestfW: Major Makefile restructuring.              */
/*             See Makefile and pin_defs.h                */
/*             (no binary changes)                        */
/*                                                        */
/* 4.6 WestfW/Pito: Add ATmega32 support                  */
/* 4.6 WestfW/radoni: Don't set LED_PIN as an output if   */
/*                    not used. (LED_START_FLASHES = 0)   */
/* Jan 2013						  */
/* 4.6 WestfW/dkinzer: use autoincrement lpm for read     */
/* 4.6 WestfW/dkinzer: pass reset cause to app in R2      */
/* Mar 2012                                               */
/* 4.5 WestfW: add infrastructure for non-zero UARTS.     */
/* 4.5 WestfW: fix SIGNATURE_2 for m644 (bad in avr-libc) */
/* Jan 2012:                                              */
/* 4.5 WestfW: fix NRWW value for m1284.                  */
/* 4.4 WestfW: use attribute OS_main instead of naked for */
/*             main().  This allows optimizations that we */
/*             count on, which are prohibited in naked    */
/*             functions due to PR42240.  (keeps us less  */
/*             than 512 bytes when compiler is gcc4.5     */
/*             (code from 4.3.2 remains the same.)        */
/* 4.4 WestfW and Maniacbug:  Add m1284 support.  This    */
/*             does not change the 328 binary, so the     */
/*             version number didn't change either. (?)   */
/* June 2011:                                             */
/* 4.4 WestfW: remove automatic soft_uart detect (didn't  */
/*             know what it was doing or why.)  Added a   */
/*             check of the calculated BRG value instead. */
/*             Version stays 4.4; existing binaries are   */
/*             not changed.                               */
/* 4.4 WestfW: add initialization of address to keep      */
/*             the compiler happy.  Change SC'ed targets. */
/*             Return the SW version via READ PARAM       */
/* 4.3 WestfW: catch framing errors in getch(), so that   */
/*             AVRISP works without HW kludges.           */
/*  http://code.google.com/p/arduino/issues/detail?id=368n*/
/* 4.2 WestfW: reduce code size, fix timeouts, change     */
/*             verifySpace to use WDT instead of appstart */
/* 4.1 WestfW: put version number in binary.		  */
/**********************************************************/

#define OPTIBOOT_MAJVER 5
#define OPTIBOOT_MINVER 0

#define MAKESTR(a) #a
#define MAKEVER(a, b) MAKESTR(a*256+b)

asm("  .section .version\n"
    "optiboot_version:  .word " MAKEVER(OPTIBOOT_MAJVER, OPTIBOOT_MINVER) "\n"
    "  .section .text\n");


#include <inttypes.h>
#include <avr/io.h>
#include <avr/pgmspace.h>

#include <stdbool.h>

// <avr/boot.h> uses sts instructions, but this version uses out instructions
// This saves cycles and program memory.
#include "boot.h"


// We don't use <avr/wdt.h> as those routines have interrupt overhead we don't need.

#include "pin_defs.h"
#include "stk500.h"

#ifndef LED_START_FLASHES
#define LED_START_FLASHES 0
#endif

#ifdef LUDICROUS_SPEED
#define BAUD_RATE 230400L
#endif

/* set the UART baud rate defaults */
#ifndef BAUD_RATE
#if F_CPU >= 8000000L
#define BAUD_RATE   115200L // Highest rate Avrdude win32 will support
#elif F_CPU >= 1000000L
#define BAUD_RATE   9600L   // 19200 also supported, but with significant error
#elif F_CPU >= 128000L
#define BAUD_RATE   4800L   // Good for 128kHz internal RC
#else
#define BAUD_RATE 1200L     // Good even at 32768Hz
#endif
#endif

#ifndef UART
#define UART 0
#endif

#define BAUD_SETTING (( (F_CPU + BAUD_RATE * 4L) / ((BAUD_RATE * 8L))) - 1 )
#define BAUD_ACTUAL (F_CPU/(8 * ((BAUD_SETTING)+1)))
#define BAUD_ERROR (( 100*(BAUD_RATE - BAUD_ACTUAL) ) / BAUD_RATE)

#if BAUD_ERROR >= 5
#error BAUD_RATE error greater than 5%
#elif BAUD_ERROR <= -5
#error BAUD_RATE error greater than -5%
#elif BAUD_ERROR >= 2
#warning BAUD_RATE error greater than 2%
#elif BAUD_ERROR <= -2
#warning BAUD_RATE error greater than -2%
#endif
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
int main(void)
{
	uint8_t ch;

	/*
	* Making these local and in registers prevents the need for initializing
	* them, and also saves space because code no longer stores to memory.
	* (initializing address keeps the compiler happy, but isn't really
	*  necessary, and uses 4 bytes of flash.)
	*/
	register uint16_t address = 0;
	register uint8_t  length;

	// After the zero init loop, this is the first code to run.
	//
	// This code makes the following assumptions:
	//  No interrupts will execute
	//  SP points to RAMEND
	//  r1 contains zero
	//
	// If not, uncomment the following instructions:
	// cli();
	asm volatile ("clr __zero_reg__");
#if defined(__AVR_ATmega8__) || defined (__AVR_ATmega32__)
	SP=RAMEND;  // This is done by hardware reset
#endif

	// Adaboot no-wait mod
	ch = MCUSR;
	MCUSR = 0;
	if (!(ch & _BV(EXTRF)))
		appStart(ch);

#if LED_START_FLASHES > 0
	// Set up Timer 1 for timeout counter
	TCCR1B = _BV(CS12) | _BV(CS10); // div 1024
#endif

#ifndef SOFT_UART
#if defined(__AVR_ATmega8__) || defined (__AVR_ATmega32__)
	UCSRA = _BV(U2X); //Double speed mode USART
	UCSRB = _BV(RXEN) | _BV(TXEN);  // enable Rx & Tx
	UCSRC = _BV(URSEL) | _BV(UCSZ1) | _BV(UCSZ0);  // config USART; 8N1
	UBRRL = (uint8_t)( (F_CPU + BAUD_RATE * 4L) / (BAUD_RATE * 8L) - 1 );
#else
	UART_SRA = _BV(U2X0); //Double speed mode USART0
	UART_SRB = _BV(RXEN0) | _BV(TXEN0);
	UART_SRC = _BV(UCSZ00) | _BV(UCSZ01);
	UART_SRL = (uint8_t)( (F_CPU + BAUD_RATE * 4L) / (BAUD_RATE * 8L) - 1 );
#endif
#endif

	// Set up watchdog to trigger after 500ms
	watchdogConfig(WATCHDOG_1S);

#if (LED_START_FLASHES > 0) || defined(LED_DATA_FLASH)
	/* Set LED pin as output */
	LED_DDR |= _BV(LED);
#endif

#ifdef SOFT_UART
	/* Set TX pin as output */
	UART_DDR |= _BV(UART_TX_BIT);
#endif

#if LED_START_FLASHES > 0
	/* Flash onboard LED to signal entering of bootloader */
	flash_led(LED_START_FLASHES * 2);
#endif

  /* Forever loop */
  while(1)
  {
		/* get character from UART */
		ch = getch();
	
		if(ch == STK_GET_PARAMETER)
		{
			unsigned char which = getch();
			verifySpace();
			if (which == 0x82) // Send optiboot version as "minor SW version"
				putch(OPTIBOOT_MINVER);
			else if (which == 0x81)
				putch(OPTIBOOT_MAJVER);
			else
				putch(0x03);
				/*
				* GET PARAMETER returns a generic 0x03 reply for
				* other parameters - enough to keep Avrdude happy
				*/
		}
		else if(ch == STK_SET_DEVICE) // SET DEVICE is ignored
			getNch(20);
		else if(ch == STK_SET_DEVICE_EXT) // SET DEVICE EXT is ignored
			getNch(5);
		else if(ch == STK_LOAD_ADDRESS)
		{
			// LOAD ADDRESS
			uint16_t newAddress;
			newAddress = getch();
			newAddress = (newAddress & 0xff) | (getch() << 8);
#ifdef RAMPZ
			// Transfer top bit to RAMPZ
			RAMPZ = (newAddress & 0x8000) ? 1 : 0;
#endif
			newAddress += newAddress; // Convert from word address to byte address
			address = newAddress;
			verifySpace();
		}
		else if(ch == STK_UNIVERSAL)
		{
			// UNIVERSAL command is ignored
			getNch(4);
			putch(0x00);
		}
		/* Write memory, length is big endian and is in bytes */
		else if(ch == STK_PROG_PAGE)
		{
			// PROGRAM PAGE - we support flash programming only, not EEPROM
			uint8_t *bufPtr = buff;

			getch();			/* getlen() */
			length = getch();
			bool memType = getch() == 'E';
	  
			//byte a = length;
			//byte* bufPtr = buff;
			//do *bufPtr++ = getch();
			//while (--length);
			//bufPtr = buff;

			//if(!memType && address < NRWWSTART)
			//	__boot_page_erase_short((uint16_t)(void*)address);

			// Moved the data buffering here so the code is less than 512B, but its slightly slower at programming flash
			buffData(length);
	  
			if(!memType)
			{
				// If we are in RWW section, immediately start page erase
				if (address < NRWWSTART)
					__boot_page_erase_short((uint16_t)(void*)address);

				// While that is going on, read in page contents
				//bufPtr = buff;
				//do *bufPtr++ = getch();
				//while (--length);
				//buffData(length);
				//buffData(length);

				// If we are in NRWW section, page erase has to be delayed until now.
				// Todo: Take RAMPZ into account (not doing so just means that we will
				//  treat the top of both "pages" of flash as NRWW, for a slight speed
				//  decrease, so fixing this is not urgent.)
				if (address >= NRWWSTART)
					__boot_page_erase_short((uint16_t)(void*)address);

				// Read command terminator, start reply
				verifySpace();

				// If only a partial page is to be programmed, the erase might not be complete.
				// So check that here
				boot_spm_busy_wait();

#ifdef VIRTUAL_BOOT_PARTITION
				if ((uint16_t)(void*)address == 0)
				{
					// This is the reset vector page. We need to live-patch the code so the
					// bootloader runs.
					//
					// Move RESET vector to WDT vector
					uint16_t vect = buff[0] | (buff[1]<<8);
					rstVect = vect;
					wdtVect = buff[8] | (buff[9]<<8);
					vect -= 4; // Instruction is a relative jump (rjmp), so recalculate.
					buff[8] = vect & 0xff;
					buff[9] = vect >> 8;

					// Add jump to bootloader at RESET vector
					buff[0] = 0x7f;
					buff[1] = 0xce; // rjmp 0x1d00 instruction
				}
#endif
				// Copy buffer into programming buffer
				//bufPtr = buff;
				uint16_t addrPtr = (uint16_t)(void*)address;
				ch = SPM_PAGESIZE / 2;
				do {
					uint16_t a;
					a = *bufPtr++;
					a |= (*bufPtr++) << 8;
					__boot_page_fill_short((uint16_t)(void*)addrPtr,a);
					addrPtr += 2;
				} while (--ch);

				// Write from programming buffer
				__boot_page_write_short((uint16_t)(void*)address);
				boot_spm_busy_wait();

#if defined(RWWSRE)
				// Reenable read access to flash
				boot_rww_enable();
#endif
			}
			else
			{
				//byte a = length;

				//bufPtr = buff;
				//do *bufPtr++ = getch();
				//while (--a);
				//buffData(length);

				// Read command terminator, start reply
				verifySpace();

				//bufPtr = buff;
				uint16_t addrPtr = address;
				do {
					loop_until_bit_is_clear(EECR, EEPE);
					EEAR = addrPtr++;
					EEDR = *bufPtr++;
					EECR |= _BV(EEMPE);
					EECR |= _BV(EEPE);
				} while(--length);
			}
		}
		else if(ch == STK_READ_PAGE) /* Read memory block mode, length is big endian.  */
		{
			// READ PAGE - we only read flash
			getch();			/* getlen() */
			length = getch();
			bool memType = getch() == 'E';

			verifySpace();
			do {
				if(!memType)
				{
#ifdef VIRTUAL_BOOT_PARTITION
					// Undo vector patch in bottom page so verify passes
					if (address == 0)
						ch = rstVect & 0xff;
					else if (address == 1)
						ch = rstVect >> 8;
					else if (address == 8)
						ch = wdtVect & 0xff;
					else if (address == 9)
						ch = wdtVect >> 8;
					else
						ch = pgm_read_byte_near(address);
					address++;
#elif defined(RAMPZ)
					// Since RAMPZ should already be set, we need to use EPLM directly.
					// Also, we can use the autoincrement version of lpm to update "address"
					//      do putch(pgm_read_byte_near(address++));
					//      while (--length);
					// read a Flash and increment the address (may increment RAMPZ)
					__asm__ ("elpm %0,Z+\n" : "=r" (ch), "=z" (address): "1" (address));
#else
					// read a Flash byte and increment the address
					__asm__ ("lpm %0,Z+\n" : "=r" (ch), "=z" (address): "1" (address));
#endif
				}
				else
				{
					EEAR = address++;
					EECR |= (1<<EERE);
					ch = EEDR;
				}
				putch(ch);
			} while (--length);
		}
		else if(ch == STK_READ_SIGN) /* Get device signature bytes  */
		{
			// READ SIGN - return what Avrdude wants to hear
			verifySpace();
			putch(SIGNATURE_0);
			putch(SIGNATURE_1);
			putch(SIGNATURE_2);
		}
		else if (ch == STK_LEAVE_PROGMODE) /* 'Q' */
		{ 
			// Adaboot no-wait mod
			watchdogConfig(WATCHDOG_16MS);
			verifySpace();
		}
		else // This covers the response to commands like STK_ENTER_PROGMODE
			verifySpace();

		putch(STK_OK);
	}
}

static void buffData(uint8_t length)
{
	uint8_t* bufPtr = buff;
	do *bufPtr++ = getch();
	while (--length);
}

static void putch(char ch) {
#ifndef SOFT_UART
  while (!(UART_SRA & _BV(UDRE0)));
  UART_UDR = ch;
#else
  __asm__ __volatile__ (
    "   com %[ch]\n" // ones complement, carry set
    "   sec\n"
    "1: brcc 2f\n"
    "   cbi %[uartPort],%[uartBit]\n"
    "   rjmp 3f\n"
    "2: sbi %[uartPort],%[uartBit]\n"
    "   nop\n"
    "3: rcall uartDelay\n"
    "   rcall uartDelay\n"
    "   lsr %[ch]\n"
    "   dec %[bitcnt]\n"
    "   brne 1b\n"
    :
    :
      [bitcnt] "d" (10),
      [ch] "r" (ch),
      [uartPort] "I" (_SFR_IO_ADDR(UART_PORT)),
      [uartBit] "I" (UART_TX_BIT)
    :
      "r25"
  );
#endif
}

static uint8_t getch(void) {
  uint8_t ch;

#ifdef LED_DATA_FLASH
#if defined(__AVR_ATmega8__) || defined (__AVR_ATmega32__)
  LED_PORT ^= _BV(LED);
#else
  LED_PIN |= _BV(LED);
#endif
#endif
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

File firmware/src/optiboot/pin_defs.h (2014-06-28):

/*------------------------------------------------------------------------ */
#if defined(__AVR_ATmega168__) || defined(__AVR_ATmega328P__) || defined(__AVR_ATmega88) || defined(__AVR_ATmega8__) || defined(__AVR_ATmega88__) || defined(__AVR_ATmega328__)
/*------------------------------------------------------------------------ */

/* Onboard LED is connected to pin PB5 in Arduino NG, Diecimila, and Duemilanove
 */ 
#if !defined(LED)
#define LED B5
#endif

/* Ports for soft UART */
#ifdef SOFT_UART
#define UART_PORT   PORTD
#define UART_PIN    PIND
#define UART_DDR    DDRD
#define UART_TX_BIT 1
#define UART_RX_BIT 0
#endif
#endif

#if defined(__AVR_ATmega8__) || defined(__AVR_ATmega32__)
  //Name conversion R.Wiersma
  #define UCSR0A	UCSRA
  #define UDR0 		UDR
  #define UDRE0 	UDRE
  #define RXC0		RXC
  #define FE0           FE
  #define TIFR1 	TIFR
  #define WDTCSR	WDTCR
#endif
#if defined(__AVR_ATmega32__)
  #define WDCE		WDTOE
#endif

/* Luminet support */
/*------------------------------------------------------------------------ */
#if defined(__AVR_ATtiny84__)
/*------------------------------------------------------------------------ */
/* Red LED is connected to pin PA4 */ 
#if !defined(LED)
#define LED         A4
#endif

/* Ports for soft UART - left port only for now. TX/RX on PA2/PA3 */
#ifdef SOFT_UART
#define UART_PORT   PORTA
#define UART_PIN    PINA
#define UART_DDR    DDRA
#define UART_TX_BIT 2
#define UART_RX_BIT 3
#endif
#endif

/*------------------------------------------------------------------------ */
/* Sanguino support (and other 40pin DIP cpus) */
#if defined(__AVR_ATmega644P__) || defined(__AVR_ATmega1284P__) || defined(__AVR_ATmega32__)
/*------------------------------------------------------------------------ */
/* Onboard LED is connected to pin PB0 on Sanguino */ 
#if !defined(LED)
#define LED         B0
#endif

/* Ports for soft UART */
#ifdef SOFT_UART
#define UART_PORT   PORTD
#define UART_PIN    PIND
#define UART_DDR    DDRD
#define UART_TX_BIT 1
#define UART_RX_BIT 0
#endif
#endif

/*------------------------------------------------------------------------ */
/* Mega support */
#if defined(__AVR_ATmega1280__)
/*------------------------------------------------------------------------ */
/* Onboard LED is connected to pin PB7 on Arduino Mega */ 
#if !defined(LED)
#define LED         B7
#endif

/* Ports for soft UART */
#ifdef SOFT_UART
#define UART_PORT   PORTE
#define UART_PIN    PINE
#define UART_DDR    DDRE
#define UART_TX_BIT 1
#define UART_RX_BIT 0
#endif
#endif

/*
 * ------------------------------------------------------------------------
 * A bunch of macros to enable the LED to be specifed as "B5" for bit 5 
 * of port B, and similar.
 */

#define A0 0x100
#define A1 0x101
#define A2 0x102
#define A3 0x103
#define A4 0x104
#define A5 0x105
#define A6 0x106
#define A7 0x107

#define B0 0x200
#define B1 0x201
#define B2 0x202
#define B3 0x203
#define B4 0x204
#define B5 0x205
#define B6 0x206
#define B7 0x207

#define C0 0x300
#define C1 0x301
#define C2 0x302
#define C3 0x303
#define C4 0x304
#define C5 0x305
#define C6 0x306
#define C7 0x307

#define D0 0x400
#define D1 0x401
#define D2 0x402
#define D3 0x403
#define D4 0x404
#define D5 0x405
#define D6 0x406
#define D7 0x407

#define E0 0x500
#define E1 0x501
#define E2 0x502
#define E3 0x503
#define E4 0x504
#define E5 0x505
#define E6 0x506
#define E7 0x507

#define F0 0x600
#define F1 0x601
#define F2 0x602
#define F3 0x603
#define F4 0x604
#define F5 0x605
#define F6 0x606
#define F7 0x607

#define G0 0x700
#define G1 0x701
#define G2 0x702
#define G3 0x703
#define G4 0x704
#define G5 0x705
#define G6 0x706
#define G7 0x707

#define H0 0x800
#define H1 0x801
#define H2 0x802
#define H3 0x803
#define H4 0x804
#define H5 0x805
#define H6 0x806
#define H7 0x807

#define J0 0xA00
#define J1 0xA01
#define J2 0xA02
#define J3 0xA03
#define J4 0xA04
#define J5 0xA05
#define J6 0xA06
#define J7 0xA07

#define K0 0xB00
#define K1 0xB01
#define K2 0xB02
#define K3 0xB03
#define K4 0xB04
#define K5 0xB05
#define K6 0xB06
#define K7 0xB07

#define L0 0xC00
#define L1 0xC01
#define L2 0xC02
#define L3 0xC03
#define L4 0xC04
#define L5 0xC05
#define L6 0xC06
#define L7 0xC07
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

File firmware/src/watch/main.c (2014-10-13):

/*
 * Project: N|Watch
 * Author: Zak Kemble, contact@zakkemble.co.uk
 * Copyright: (C) 2013 by Zak Kemble
 * License: GNU GPL v3 (see License.txt)
 * Web: http://blog.zakkemble.co.uk/diy-digital-wristwatch/
 */

#include "common.h"

static void init(void);
#if WDT_ENABLE && WDT_DEBUG
static void resetError(void);
#else
#define resetError() (EMPTY_FUNC)
#endif
//static void configError(void);
//static void freeRAM(void);

int main(void)
{
	init();

	sei();

	if(wdt_wasReset())
		resetError();
	//else if(!appconfig_check())
	//	configError();

	// Startup buzz and flash
	buzzer_buzz(200, TONE_4KHZ, VOL_UI, PRIO_UI, NULL);
	led_flash(LED_GREEN, 50, 255);

	// Set watchface
	display_set(watchface_normal);
	display_load();
	
	while(1)
	{
		time_update();
		if(pwrmgr_userActive())
		{
			battery_update();
			buttons_update();
		}

		buzzer_update();
		led_update();
#if COMPILE_STOPWATCH
		stopwatch_update();
#endif
		global_update();

		if(pwrmgr_userActive())
		{
			alarm_update();
			display_update();
		}

//		freeRAM();

		wdt_update();

		pwrmgr_update();
	}
}

static void init()
{
//	OSCCAL = 71;

#if CPU_DIV != clock_div_1
	clock_prescale_set(CPU_DIV);
#endif

//	power_twi_disable();
//	power_usart0_disable();
//	power_timer0_disable();
//	power_timer1_disable();
//	power_timer2_disable();
//	power_adc_disable();

#if PIN_DEBUG != PIN_DEBUG_NONE
	pinMode(PIN_DEBUG_PIN, OUTPUT);
#endif

	// Everything else
	global_init();
	uart_init();
	spi_init();
	i2c_init();
	adc_init();
	appconfig_init();
	led_init();
	buzzer_init();
	battery_init();
	buttons_init();
	millis_init();
	rtc_init();
	pwrmgr_init();
	time_init();
	alarm_init();
	oled_init();
}

#if WDT_ENABLE && WDT_DEBUG
static void resetError()
{
	while(1)
	{
		wdt_update();
		buzzer_buzzb(200,TONE_5KHZ, VOL_UI);
		buzzer_buzzb(200,TONE_2_5KHZ, VOL_UI);
		buzzer_buzzb(200,TONE_3KHZ, VOL_UI);
	}
}
#endif
/*
static void configError()
{
	oled_power(OLED_PWR_OFF);
	while(1)
	{
		if(!led_flashing())
		{
			delay(300);
			led_flash(LED_RED, 50, 255);
		}
		led_update();
	}
}
*/
/*
void freeRAM(void)
{
	extern int __heap_start, *__brkval;
	int v;
	int free = (int) &v - (__brkval == 0 ? (int) &__heap_start : (int) __brkval);
	printf("Free RAM : %d\n", free);
}
*/

// USB plugged in uses PCINT0/2 to wake up
// Buttons use PCINT1 to wake up, alias is used to save a few bytes
#if HW_VERSION == 3
EMPTY_INTERRUPT(PCINT2_vect);
ISR(PCINT1_vect, ISR_ALIASOF(PCINT2_vect));
#else
EMPTY_INTERRUPT(PCINT0_vect);
ISR(PCINT1_vect, ISR_ALIASOF(PCINT0_vect));
#endif

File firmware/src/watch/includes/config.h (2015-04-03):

/*
 * Project: N|Watch
 * Author: Zak Kemble, contact@zakkemble.co.uk
 * Copyright: (C) 2013 by Zak Kemble
 * License: GNU GPL v3 (see License.txt)
 * Web: http://blog.zakkemble.co.uk/diy-digital-wristwatch/
 */

// Fuses for ATmega328/328P
// Internal RC 8MHz 6 CK/14CK + 4.1ms startup
// Serial program (SPI) enabled
// Brown-out at 1.8V
// High:		0xDF
// Low:			0xD2
// Extended:	0xFE

#ifndef CONFIG_H_
#define CONFIG_H_

// Hardware version
// 1 = PCB 1.0 - 1.1
// 2 = PCB 1.2
// 3 = PCB 1.3 - 1.4
#define HW_VERSION	3

// Firmware version
#define FW_VERSION	"1.1 141115" // maybe use some __DATE__ __TIME__ stuff?

// Language
// 0 = English
// 1 = German (not done)
// 2 = Russian
#define LANGUAGE 0

// OLED Controller chip
// OLED_CONTROLLER_SSD1306
// OLED_CONTROLLER_SH1106
#define OLED_CONTROLLER OLED_CONTROLLER_SSD1306

// Compile options
#define COMPILE_GAME1 1 // Breakout
#define COMPILE_GAME2 1 // Car dodge
#define COMPILE_GAME3 0 // Flappy thing (not finished)
#define COMPILE_ANIMATIONS 1
#define COMPILE_STOPWATCH 1
#define COMPILE_TORCH 1
#define COMPILE_BTRCCAR 0
#define COMPILE_UART 0
#define COMPILE_SCREENSHOT 0


#define COMPILE_I2C 1


//#define UART_BAUD 76800
//#define ALARM_COUNT 10

// Only DS3231 is working at the moment
#define RTC_SRC_INTERNAL	0
#define RTC_SRC_DS3231		1
#define RTC_SRC_DS1307		2
#define RTC_SRC_MCP7940X	3

#define RTC_SRC RTC_SRC_DS3231


#define DEBUG_MSGS				0

#define PIN_DEBUG_NONE			0
#define PIN_DEBUG_DRAW			1
#define PIN_DEBUG_SLEEP_IDLE	2
#define PIN_DEBUG_SLEEP_PWRDOWN	3
#define PIN_DEBUG_SPI			4

#define PIN_DEBUG				PIN_DEBUG_NONE

#if HW_VERSION == 3
#define PIN_DEBUG_PIN	B6
#else
#define PIN_DEBUG_PIN	D4
#endif

#endif /* CONFIG_H_ */

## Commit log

2014-06-28 Lots of stuff
    Software:
    - Added a bootloader (slightly modified Optiboot, added support for
    ATmega328 non-P and reading/writing EEPROM)
    - Reduced flash and RAM usage (Flash: 29156 -> 26702 (2454), RAM: 1407
    -> 1300 (107))
    - Added support for playing tunes
    - Alarms are loaded from EEPROM as needed instead of having them hanging
    around in RAM all the time
    - Lots of bug fixes, heres some:
    Wonkiness if EEPROM wasn't programmed
    Alarms not going off on the correct day
    If an alarm goes off but is not cancelled by the user the watch would
    stay on
    Watch waking up when it's not supposed to
    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
    [watch.brd, watch.sch, watchPogoSerial.brd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]
2014-06-30 Fixed tune priority not resetting
    Also added new lines to end of files
    [adc.c, battery.c]
2014-07-01 Schematic adjustments
    D1 was ZLLS410, should be BAT60JFILM
    [watch.brd, watch.sch]
2014-10-13 Hardware updated
    N|Watch (v1.4):
    - Q2, Q3, Q4 MOSFETs changed to BJTs (BC817-40 & BC807-40)
    - R2, R3 100R gate resistors changed to 47K and 1K
    - R4 has been removed (now all resistors in RN3 are being using)
    [watch.brd, watch.sch, watchPogoSerial.brd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]
2014-10-13 Added early battery undervoltage cutoff
    - Added early battery undervoltage cutoff. Improves battery lifespan by
    not letting the voltage go so low and the RTC will continue working
    since the battery's own PCM hasn't kicked in yet
    - Slightly reduced power consumption by going into power save sleep
    instead of idle sleep if no other peripherals are in use
    - Various code optimisations
2014-10-29 12 hour mode, Russian translation
    Added 12 hour time option
    Russian translation, thanks to Onatsky Sergei (Le_Fleurs (-at-) mail
    (-dot-) ru)
    Bootloader baud changed from 76800 to 57600 (Linux doesn't like 76800)
    [battery.c, config.h]
2014-11-08 Updated Russian translation & added N|WatchDev
    Updated Russian translation (day of week images)
    Released N|WatchDev designs (dev board version of the watch)
    [watch_dev.brd, watch_dev.sch]
2014-11-15 Fixed issue for when RTC isn't connected
    [config.h]

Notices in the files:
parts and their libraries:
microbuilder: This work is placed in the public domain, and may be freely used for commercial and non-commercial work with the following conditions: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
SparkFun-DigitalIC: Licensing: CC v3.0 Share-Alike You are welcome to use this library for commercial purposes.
